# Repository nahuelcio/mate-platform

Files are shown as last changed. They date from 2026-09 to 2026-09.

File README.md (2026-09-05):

# mate-platform 🧉

IoT platform for smart mate sharing sessions powered by ESP32, embedded sensors, web server API, and MCP notification agent for Claude Code and chat channels.

---

## Overview

`mate-platform` automates round management for drinking mate:
- **Automatic turn passing:** When the mate is picked up from the dock base, a timer starts. Once placed back on the dock, the round advances automatically to the next person.
- **Hold alarm:** If a participant retains the mate longer than the allowed duration, an acoustic alarm sounds through the buzzer and displays a warning on the OLED screen.
- **Automated tilt mechanism:** An SG90 micro-servo tilts the base to 45° to assist with water pouring and herbal infusion positioning.
- **Voice integration ("Thanks" detection):** When someone says *"gracias"*, they leave the round, and the turn advances.
- **Notifications & Chat:** Multi-channel notification watcher (macOS native banners, Discord, Slack, Telegram) and Model Context Protocol (MCP) server for Claude Code.

---

## Hardware Components & Pinout

ESP32 DOIT 30-PIN Dev Board configuration:

| Component | Function | ESP32 Pins | Protocol / Mode |
| :--- | :--- | :--- | :--- |
| **SSD1306 (0.96" OLED)** | Turn display, timer & alert banner | `SDA: GPIO 21`, `SCL: GPIO 22` | I2C (`0x3C`) |
| **GY-521 (MPU6050)** | Accelerometer & gyro for tilt detection | `SDA: GPIO 21`, `SCL: GPIO 22` | I2C (`0x68`) |
| **SG90 Micro Servo** | Automatic 45° tilt mechanism | `PWM: GPIO 13`, `VIN (5V)`, `GND` | PWM |
| **HC-SR04** | Ultrasonic proximity sensor | `TRIG: GPIO 5`, `ECHO: GPIO 18` | Digital I/O |
| **GY-MAX9814** | Microphone with automatic gain | `OUT: GPIO 35` (ADC1), `3V3`, `GND` | Analog (ADC1 safe with Wi-Fi) |
| **Active Buzzer** | Acoustic anti-delay alarm | `GPIO 19`, `GND` | Digital / PWM `tone()` |
| **Base Dock Switch** | Mate present / lifted detection | `GPIO 4`, `GND` | Digital In (`INPUT_PULLUP`) |

---

## REST API (ESP32 Web Server)

| Method | Endpoint | Description |
| :--- | :--- | :--- |
| `GET` | `/status` | Returns round status, current turn, dock state, distance, and participant list |
| `POST` | `/round/config` | Sets participant names: `{"names": ["Nahuel", "Santi", "Flor"]}` |
| `POST` | `/round/thanks` | Removes participant who said thanks: `?name=Nahuel` |
| `POST` | `/round/next` | Manually advances to the next turn |
| `POST` | `/servo/tilt` | Adjusts SG90 tilt angle: `?angle=45` |

---

## Claude Code MCP Integration (`mcp-mate-platform`)

The included MCP server exposes tools directly to Claude Code.

### Available Tools:
1. `mate_status`: Consultar estado del mate y a quién le toca.
2. `mate_tilt_pour`: Inclinar el mate a 45° con el servo para cebar.
3. `mate_thanks`: Registrar que alguien dijo "gracias" y retirarlo de la ronda.
4. `mate_next`: Pasar el turno manualmente.
5. `mate_configure`: Configurar la lista de personas de la ronda.

### Registering with Claude Code:

```bash
claude mcp add mate-platform -- node /path/to/mate-platform/mcp-mate-platform/dist/index.js
```

For real hardware over local Wi-Fi, specify the target IP:
```bash
claude mcp add mate-platform -- node /path/to/mate-platform/mcp-mate-platform/dist/index.js --env MATE_PLATFORM_URL=http://192.168.1.50
```

### Notifications & Chat Watcher (macOS, Discord, Slack, Telegram):

Run in a background terminal:
```bash
cd mcp-mate-platform

# With optional Chat Webhooks:
export DISCORD_WEBHOOK_URL="https://discord.com/api/webhooks/..."
export SLACK_WEBHOOK_URL="https://hooks.slack.com/services/..."

npm run notify -- --sound --pomodoro 3
```

---

## Simulation with Wokwi

1. Open `diagram.json` in VS Code.
2. Press `F1` / `Cmd + Shift + P` and select **`Wokwi: Start Simulator`**.
3. Ports are forwarded automatically to `http://localhost:8180`.

---

## License

MIT

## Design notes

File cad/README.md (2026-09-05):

# mate-platform: 3D CAD Blueprint & Assembly Guide

Este documento detalla la arquitectura mecánica, despiece, tolerancias y especificaciones para fabricar las piezas de la estación inteligente de mate en impresión 3D (FDM / SLA) o para su importación directa en Shapr3D.

---

## 1. Arquitectura del Conjunto (4 Módulos)

```
                       [ MATE / CALABAZA ]
                                │
                      (Pulsador de Presencia)
                                │
    ┌────────────────────────────────────────────────────────┐
    │  PIEZA 1: Cuna Basculante 45° (Tilting Cradle)         │
    │  - Asiento cónico Ø 78 mm para el mate                 │
    │  - Pernos de pivote Ø 6 mm integrados                  │
    │  - Alojamiento inferior para IMU GY-521 (MPU6050)      │
    │  - Ojo de biela para brazo de servo SG90               │
    └───────────────────────────┬────────────────────────────┘
                                │ Eje de Giro (Pivote 45°)
    ┌───────────────────────────┴────────────────────────────┐
    │  PIEZA 2: Carcasa Superior & Sensores (Sensor Fascia)  │
    │  - Bisel para Pantalla OLED SSD1306 a 30°              │
    │  - Soportes cilíndricos para HC-SR04 (ojos ultrasonido)│
    │  - Guía acústica para micrófono GY-MAX9814             │
    │  - Bancadas de apoyo para los pernos de giro           │
    └───────────────────────────┬────────────────────────────┘
                                │ Encastre M3 / Snap-Fit
    ┌───────────────────────────┴────────────────────────────┐
    │  PIEZA 3: Chasis Principal (Main Enclosure Base)       │
    │  - Cuna y correderas para placa ESP32 (30 pines)       │
    │  - Bahía de fijación rígida para Micro Servo SG90      │
    │  - Cámara acústica de resonancia para Buzzer 12mm      │
    │  - Pasacables internos con amarre para zunchos         │
    │  - Salida trasera para cable Micro-USB / Type-C        │
    └───────────────────────────┬────────────────────────────┘
                                │ 4x Tornillos M3 avellanados
    ┌───────────────────────────┴────────────────────────────┐
    │  PIEZA 4: Tapa Inferior de Servicio (Bottom Lid)       │
    │  - Ranuras de ventilación tipo persiana (louver vents) │
    │  - 4x Alojamientos para patas de silicona (Ø 12 x 2 mm)│
    │  - Acceso directo para mantenimiento y cableado        │
    └────────────────────────────────────────────────────────┘
```

---

## 2. Dimensiones y Medidas Críticas (Nominales & Tolerancias)

| Componente | Medida Real (mm) | Tolerancia 3D (Cavitación) | Detalle de Encastre |
| :--- | :--- | :--- | :--- |
| **Mate / Vaso** | Ø 60 a 76 mm | Asiento Ø 78 mm cónico | Admite mates de calabaza, madera o acero térmico |
| **ESP32 DOIT 30-Pin** | 51.5 x 28.5 x 12.0 mm | Riel de 52.5 x 29.5 mm (+1.0mm) | Deslizamiento suave sobre guías laterales |
| **OLED 0.96" SSD1306** | 27.0 x 27.5 x 3.5 mm | Bisel de 24.5 x 14.5 mm (área activa) | Inclinado a 30° hacia el usuario para lectura fácil |
| **Servo SG90** | 22.8 x 12.2 x 24.5 mm | Bolsillo de 23.5 x 12.8 mm (+0.6mm) | Fijado con orejeras de 2 tornillos M2 |
| **Sensor HC-SR04** | 45.2 x 20.4 mm, conos Ø 16 mm | 2x orificios de Ø 16.5 mm c-to-c 26 mm | Alojamiento a presión frontal para censar presencia |
| **Micrófono GY-MAX9814** | 25.5 x 14.2 mm, cápsula Ø 6mm | Cavidad frontal + rejilla acústica | Aislado mecánicamente de la vibración del servo |
| **Buzzer 12mm** | Ø 12.0 mm x 9.5 mm | Cámara resonante Ø 14.0 mm | Salida de audio acústica en la base |
| **Switch Base (Dock)** | KW12 (19.8 x 6.4 x 10.2 mm) | Soporte con resorte de retorno | Se activa con > 25 g al apoyar el mate |

---

## 3. Archivos STL Generados y Listos para Imprimir

Ubicación: `/cad/models/`

1. **`01_tilting_cradle_45deg.stl`**
   - Peso estimado: ~28 g PLA.
   - Tiempo de impresión: ~1h 45m.
   - Soportes recomendados: Soportes tipo árbol solo en los pernos de pivote.
2. **`02_main_enclosure_base.stl`**
   - Peso estimado: ~65 g PLA.
   - Tiempo de impresión: ~3h 30m.
   - Infill: 20% Gyroid (para máxima rigidez y resonancia del buzzer).
3. **`03_upper_sensor_fascia.stl`**
   - Peso estimado: ~38 g PLA.
   - Tiempo de impresión: ~2h 15m.
   - Permite montar la pantalla inclinada y los sensores frontales.
4. **`04_bottom_service_lid.stl`**
   - Peso estimado: ~22 g PLA.
   - Tiempo de impresión: ~1h 10m.
   - Fondo plano, no requiere soportes.

---

## 4. Parámetros de Impresión Recomendados (FDM)

- **Material:** PLA, PLA+ o PETG (recomendado PETG si se expone a salpicaduras de agua caliente).
- **Altura de capa:** `0.20 mm` (ó `0.16 mm` para mejor acabado en las curvas de la cuna).
- **Perímetros (Paredes):** 4 a 6 perímetros (`1.6 mm - 2.4 mm`) para tornillos e insertos de rosca M3.
- **Relleno (Infill):** `20% - 25%` Gyroid o Honeycomb.
- **Insertos:** Agujeros preparados para insertos de latón M3 (roscado en caliente / calor con cautín).

---

## 5. Edición y Ajustes Paramétricos

Para regenerar o cambiar cualquier medida (por ejemplo ampliar el diámetro del mate a 85mm o ajustar el ángulo del display):
```bash
python3 cad/generator.py
```
El script exporta los binarios STL estándar que pueden abrirse directamente en **Shapr3D**, **Bambu Studio**, **PrusaSlicer**, **OrcaSlicer** o **Cura**.

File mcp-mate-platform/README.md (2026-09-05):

# mcp-ymate 🧉

Servidor **MCP** para que **Claude Code** (y Claude Desktop) controlen el **ESP32 yMate** — el mate con ronda automática, sensor de apoyo, servo de cebado y alerta de demora.

Habla con el webserver del ESP32 (proyecto en `../esp32`, simulado con Wokwi):

| Endpoint del ESP32 | Uso |
|---|---|
| `GET /status` | Estado de la ronda |
| `POST /ronda/config` | Armar ronda: `{ "nombres": [...] }` |
| `POST /ronda/gracias` | Sacar a quien dijo gracias (`?nombre=` o el actual) |
| `POST /servo/mover` | Inclinar el servo (`?angulo=`, 0–90, default 45) |

> Importante: el firmware lee los parámetros con `server.arg()`, que se resuelve
> con el **query string**. Este cliente manda los parámetros por query y además
> repite el body JSON para máxima compatibilidad.

## Requisitos

- Node.js ≥ 18 (probado con Node 26)
- La simulación de Wokwi corriendo con el reenvío `localhost:8180 → target:80`,
  o el ESP32 real en tu red (usá `YMATE_BASE_URL`)

## Instalación

```bash
cd /Users/nahuelcioffi/Proyectos/esp32/mcp-ymate
npm install
npm run build     # genera dist/
```

## Registrarlo en Claude Code

### Opción A: `claude mcp add` (recomendada)

```bash
# Si el ESP32 está simulado en localhost:8180 (Wokwi):
claude mcp add ymate -- node /Users/nahuelcioffi/Proyectos/esp32/mcp-ymate/dist/index.js

# Si el ESP32 real está en tu red:
claude mcp add ymate --env YMATE_BASE_URL=http://192.168.1.50 -- node /Users/nahuelcioffi/Proyectos/esp32/mcp-ymate/dist/index.js

# Alcance: --scope local (solo este proyecto) o --scope user (todos tus proyectos)
```

### Opción B: `.mcp.json` en la raíz del proyecto

```json
{
  "mcpServers": {
    "ymate": {
      "command": "node",
      "args": ["/Users/nahuelcioffi/Proyectos/esp32/mcp-ymate/dist/index.js"],
      "env": { "YMATE_BASE_URL": "http://localhost:8180" }
    }
  }
}
```

### Opción C: config global de Claude Code

```bash
claude mcp add --scope user ymate -- node /Users/nahuelcioffi/Proyectos/esp32/mcp-ymate/dist/index.js
```

### Registrarlo en Claude Desktop

`claude_desktop_config.json` (macOS: `~/Library/Application Support/Claude/claude_desktop_config.json`):

```json
{
  "mcpServers": {
    "ymate": {
      "command": "node",
      "args": ["/Users/nahuelcioffi/Proyectos/esp32/mcp-ymate/dist/index.js"],
      "env": { "YMATE_BASE_URL": "http://localhost:8180" }
    }
  }
}
```

Verificá con `claude mcp list` (Claude Code) o reiniciá Claude Desktop.

## Herramientas MCP

| Herramienta | Qué hace |
|---|---|
| `mate_status` | Estado de la ronda: quién tiene el turno, si el mate está apoyado o en mano, alerta de demora, distancia y participantes |
| `mate_cebar` | Inclina el servo (ceba el mate). `{ angulo?: 0–90 }`, default 45 |
| `mate_gracias` | Registra el "gracias" de alguien y lo saca de la ronda. `{ nombre?: string }`, default: el actual |
| `mate_siguiente` | Pasa el turno al siguiente (rota la lista vía `/ronda/config`) |
| `mate_configurar` | Arma una ronda nueva. `{ nombres: string[] }` (máx. 10) |

Después de registrarlo, decile a Claude algo como:

> Usá `mate_status`, pasale el turno a Santi con `mate_siguiente` y cebá con `mate_cebar`.

## Notificador / Pomodoro matero (terminal)

Un proceso aparte que vigila `/status` cada pocos segundos y avisa por consola
cuando alguien levanta el mate, lo devuelve, cambia el turno o salta la alerta
de demora. Con `--pomodoro MIN` recuerda pasar el mate cada `MIN` minutos.

```bash
npm run notify                                  # vigila cada 5 s
npm run notify -- --interval 10 --pomodoro 3 --sound
npm run notify -- --once                        # imprime el estado y sale (útil para hooks)
YMATE_BASE_URL=http://192.168.1.50 npm run notify
```

### Como hook de Claude Code

Para que un agente "matero" vigile la ronda en background, agregá esto a tu
`.claude/settings.json` (o la config de tu proyecto):

```json
{
  "hooks": {
    "PreToolUse": [
      {
        "matcher": "Bash(npm run notify|node .*pomodoro)",
        "hooks": [
          {
            "type": "command",
            "command": "node /Users/nahuelcioffi/Proyectos/esp32/mcp-ymate/dist/pomodoro.js --once"
          }
        ]
      }
    ]
  }
}
```

O simplemente dejalo corriendo en otra pestaña de la terminal con `npm run notify`.

## Desarrollo y verificación

```bash
npm run mock      # mock del ESP32 en http://localhost:8180 (replica main.cpp)
npm run smoke     # test E2E: mock + handshake MCP por stdio + las 5 herramientas
npm run notify -- --once   # prueba el notificador contra el mock
```

La base URL se resuelve así: `YMATE_BASE_URL` → `ESP32_URL` → `http://localhost:8180`.

## Estructura

```
mcp-ymate/
├── src/
│   ├── index.ts       # servidor MCP (stdio) con las 5 herramientas
│   ├── client.ts      # cliente HTTP contra el ESP32 (query + body)
│   ├── config.ts      # resolución de YMATE_BASE_URL y tipos
│   └── pomodoro.ts    # notificador / pomodoro matero en terminal
├── scripts/
│   ├── mock-esp32.js  # mock fiel del firmware para desarrollo
│   └── smoke.mjs      # smoke test end-to-end por stdio
├── package.json
└── tsconfig.json
```

## Solución de problemas

- **"No hay respuesta del ESP32"**: la simulación de Wokwi no está corriendo, o el
  ESP32 real está en otra IP. Ajustá `YMATE_BASE_URL`.
- **No aparecen las herramientas**: reiniciá Claude Code / Claude Desktop después
  de registrar el server, y verificá con `claude mcp list`.
- **El ángulo no cambia con body JSON**: el firmware usa `server.arg()`, que
  prioriza el query string; este cliente siempre manda `?angulo=` también.

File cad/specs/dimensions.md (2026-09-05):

# Mechanical Dimensions & Component Tolerances

All dimensions in millimeters (mm). Tolerances for FDM 3D printing (PLA/PETG, 0.4mm nozzle, 0.2mm layer height) included.

---

## 1. Electronic Components Dimensions

### 1.1 ESP32 DOIT DevKit V1 (30-pin)
- PCB Outline: `51.5 mm (L) × 28.5 mm (W) × 12.0 mm (H)` (including pin headers).
- Pin pitch: `2.54 mm`. Row spacing: `25.4 mm (1.0")`.
- Micro-USB connector protrusion: `1.5 mm` beyond PCB edge.
- Mounting hole spacing: `46.0 mm × 23.0 mm`, hole diameter: `2.8 mm` (for M2.5 / self-tapping screws).
- Clearance envelope for cad cradle: `53.0 mm × 30.0 mm × 14.0 mm`.

### 1.2 SSD1306 0.96" OLED I2C Display
- PCB Size: `27.0 mm (W) × 27.5 mm (H) × 3.5 mm (D)`.
- Active glass screen: `24.0 mm × 14.0 mm` (viewable area: `21.74 mm × 10.86 mm`).
- Screen offset from PCB top: `4.5 mm`.
- Mounting holes: 4× `M2` holes (`2.0 mm`), center-to-center: `23.0 mm (W) × 23.5 mm (H)`.
- Front bezel cutout required: `24.5 mm × 14.5 mm`, inner recess depth `1.8 mm`.

### 1.3 SG90 Micro Servo
- Body Dimensions: `22.8 mm (L) × 12.2 mm (W) × 24.5 mm (H)` (overall height with output spline: `28.5 mm`).
- Mounting flange: `32.0 mm (L) × 12.2 mm (W) × 2.5 mm (T)` at height `16.0 mm` from base.
- Flange mounting screw pitch: `28.0 mm` (2× holes, `2.0 mm` dia).
- Output shaft center: `5.5 mm` from one edge, diameter `4.8 mm` (21T spline).
- Horn swing radius: `15.0 mm` clearance envelope.

### 1.4 GY-521 (MPU6050 6-DoF IMU)
- PCB Dimensions: `20.5 mm (L) × 15.6 mm (W) × 3.2 mm (H)`.
- Mounting holes: 2× `M3` holes (`3.0 mm` dia) spaced `15.0 mm` apart.
- Placement: Mounted directly under the tilting cradle to track real inclination.

### 1.5 HC-SR04 Ultrasonic Distance Sensor
- PCB Dimensions: `45.2 mm (L) × 20.4 mm (W) × 15.0 mm (H)`.
- Transducers (Transmitter + Receiver): 2× cylinders, `16.0 mm` outer diameter each.
- Transducer center-to-center distance: `26.0 mm`.
- Transducer protrusion above PCB: `12.5 mm`.
- Front plate cutouts: 2× `16.5 mm` circular holes spaced `26.0 mm` center-to-center.

### 1.6 GY-MAX9814 Microphone Module
- PCB Dimensions: `25.5 mm (L) × 14.2 mm (W) × 8.0 mm (H)`.
- Mic capsule diameter: `6.0 mm`, protrusion: `3.0 mm`.
- Front sound grille aperture: 3× `1.5 mm` acoustic slot array.

### 1.7 Passive/Active Buzzer Module (12mm)
- Body: Cylinder `12.0 mm` diameter × `9.5 mm` height.
- Sound port: `2.0 mm` central top hole.
- Internal acoustic cavity: `14.0 mm` chamber with sound director funnel.

### 1.8 Microswitch / Limit Switch (Dock Sensor)
- KW12 / Omron style micro lever switch: `19.8 mm (L) × 6.4 mm (W) × 10.2 mm (H)`.
- Lever arm length: `18.0 mm` with roller or curved tip.
- Actuation stroke: `1.2 mm - 1.8 mm`.
- Pre-travel contact: Triggered by 25g+ mate weight resting on dock plate.

---

## 2. Platform Architecture (4 Main Assemblies)

```
       +---------------------------------------------+
       |             MATE CUP (Calabaza/Termo)       |
       +---------------------------------------------+
                            |
                   [Dock Switch Lever]
                            |
  +-------------------------------------------------------+
  |  PART 1: Tilting Cradle (Cuna Basculante 45°)         |
  |  - Inner Ø 78 mm cup seat                             |
  |  - Built-in GY-521 IMU pocket                         |
  |  - Pivot trunnion pins (Ø 6 mm)                       |
  |  - Servo push-rod linkage receiver                    |
  +-------------------------------------------------------+
                            |
          Pivot Axis (Ø 6mm Pin) + SG90 Servo Arm
                            |
  +-------------------------------------------------------+
  |  PART 2: Upper Housing & Sensor Ring                  |
  |  - HC-SR04 dual front apertures (Ø 16.5 mm)           |
  |  - SSD1306 0.96" OLED bezel angled at 30°             |
  |  - Mic acoustic duct for GY-MAX9814                   |
  |  - Trunnion pivot supports (Left & Right)             |
  +-------------------------------------------------------+
                            |
                    Snap-fit / M3 Standoffs
                            |
  +-------------------------------------------------------+
  |  PART 3: Main Base Enclosure (Cuerpo Principal)       |
  |  - ESP32 slide-in rails with USB-C / micro-USB port   |
  |  - SG90 servo rigid pocket & cable raceways           |
  |  - Internal cable routing channels & tie anchors      |
  |  - Buzzer resonant sound chamber                      |
  +-------------------------------------------------------+
                            |
                    4x M3 Threaded Inserts
                            |
  +-------------------------------------------------------+
  |  PART 4: Bottom Service Lid (Tapa Inferior)           |
  |  - 4x Non-slip rubber feet recesses (Ø 10 mm x 2 mm)  |
  |  - Passive cooling vents (angled louvers)             |
  |  - Access to reset/boot buttons                       |
  +-------------------------------------------------------+
```

---

## 3. Clearances & 3D Print Tolerances

- **FDM Press-fit (tight):** Component nominal + `0.15 mm`.
- **FDM Sliding-fit / Pivot:** Shaft nominal - `0.20 mm`, Hole nominal + `0.25 mm` (Total clearance `0.45 mm`).
- **Snap-fit cantilever tabs:** Width `5.0 mm`, thickness `1.6 mm`, length `12.0 mm`, hook depth `0.8 mm`.
- **Wall thickness guidelines:**
  - Structural outer shell: `2.4 mm` (6 perimeters with 0.4mm nozzle).
  - Internal ribs & dividers: `1.6 mm` (4 perimeters).
  - Component cradle clips: `1.2 mm`.
- **M3 Threaded heat-set inserts:** Hole diameter `4.2 mm`, depth `5.5 mm`.

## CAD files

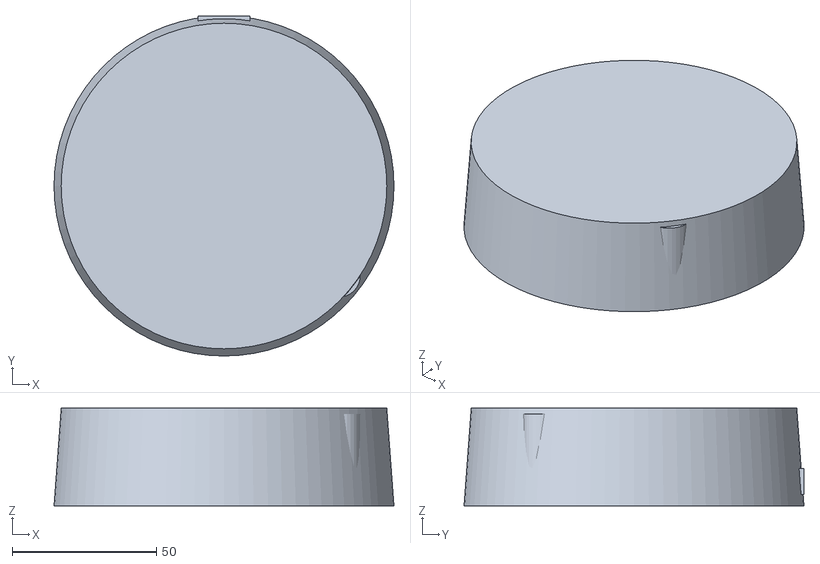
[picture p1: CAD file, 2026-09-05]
cad/models/02_main_enclosure_base.stl
118.0 x 118.0 x 34.0

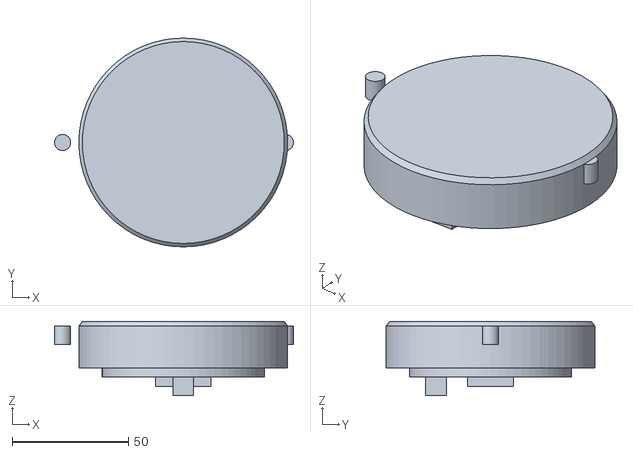
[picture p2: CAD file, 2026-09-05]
cad/models/01_tilting_cradle_45deg.stl
103.0 x 90.0 x 32.0

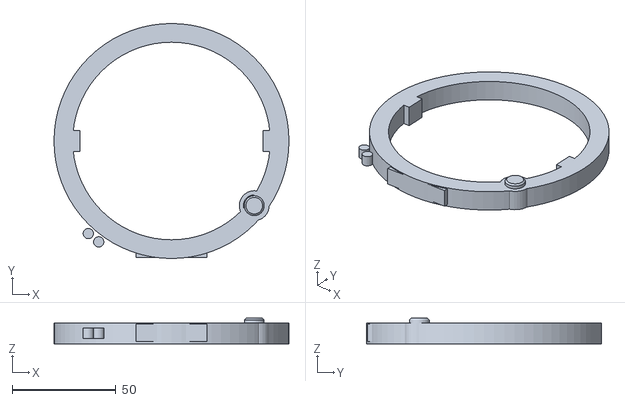
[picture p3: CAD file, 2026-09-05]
cad/models/03_upper_sensor_fascia.stl
113.0 x 113.0 x 12.3

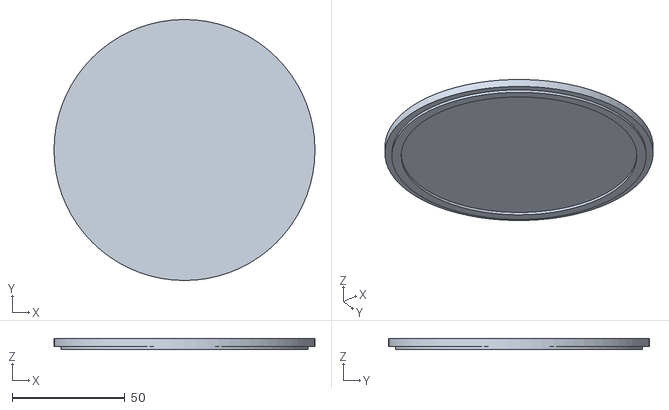
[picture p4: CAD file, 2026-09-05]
cad/models/04_bottom_service_lid.stl
116.0 x 116.0 x 4.70

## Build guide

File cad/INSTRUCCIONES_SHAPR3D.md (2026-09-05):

# Importar en Shapr3D - mate-platform

La ventana de Finder ya está abierta con los 4 archivos STL:
`/Users/nahuelcioffi/Proyectos/esp32/cad/models`

## Pasos rápidos en Shapr3D:

1. En Shapr3D, hace clic en **"New design"** (o **Cmd + N**).
2. Seleccioná los 4 archivos en la ventana de Finder que tenés abierta:
   - `01_tilting_cradle_45deg.stl`
   - `02_main_enclosure_base.stl`
   - `03_upper_sensor_fascia.stl`
   - `04_bottom_service_lid.stl`
3. **Arrastralos y soltalos (Drag & Drop)** directamente adentro del lienzo 3D de Shapr3D.
   - O desde el menú: **File > Import...** (o **Cmd + I**) y elegí los archivos de esa carpeta.

## Unidades al importar:
- Elegí **Millimeters (mm)** si te pregunta.

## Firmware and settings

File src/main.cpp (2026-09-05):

#include <Arduino.h>
#include <WiFi.h>
#include <WebServer.h>
#include <Wire.h>
#include <Adafruit_GFX.h>
#include <Adafruit_SSD1306.h>
#include <Adafruit_MPU6050.h>
#include <Adafruit_Sensor.h>
#include <ESP32Servo.h>
#include <ArduinoJson.h>

// --- OLED SSD1306 DISPLAY (I2C) ---
#define SCREEN_WIDTH 128
#define SCREEN_HEIGHT 64
Adafruit_SSD1306 display(SCREEN_WIDTH, SCREEN_HEIGHT, &Wire, -1);

// --- GY-521 (MPU6050) ACCELEROMETER / GYROSCOPE ---
Adafruit_MPU6050 mpu;
bool mpuAvailable = false;

// --- SG90 MICRO SERVO (TILT / POURING MECHANISM) ---
Servo sg90;
const int PIN_SERVO_SG90 = 13;

// --- HC-SR04 ULTRASONIC SENSOR ---
const int PIN_TRIG = 5;
const int PIN_ECHO = 18;

// --- GY-MAX9814 MICROPHONE (ANALOG OUT) ---
// Dedicated ADC1 input pin on ESP32 (safe to use while Wi-Fi is active)
const int PIN_MIC_OUT = 35;

// --- BUZZER / SPEAKER (DELAY ALARM) ---
const int PIN_BUZZER = 19;

// --- STATUS LED / BREATHING RING (INDICATOR) ---
// Solid green/blue: ready/docked. Breathing blue: drinking. Blinking red: delay alarm!
const int PIN_LED_STATUS = 2;

// --- BASE DOCK SWITCH (MECHANICAL / BUTTON INPUT) ---
const int PIN_BTN_BASE = 4;

// --- MULTIFUNCTION PHYSICAL BUTTON (ALUMINUM CROWN) ---
// Short press: manual next turn ("mate_next")
// Long press (>2s): mute alarm / toggle round pause
const int PIN_BTN_ACTION = 15;
unsigned long btnActionPressTime = 0;
bool btnActionLastState = HIGH;

WebServer server(80);

// --- ROUND / SESSION STATE ---
#define MAX_PARTICIPANTS 10
String participants[MAX_PARTICIPANTS] = {"Nahuel", "Santi", "Flor", "Mati"};
int totalParticipants = 4;
int currentTurn = 0;

bool mateOnDock = true;
bool delayAlarmActive = false;
unsigned long liftedTimestamp = 0;
const unsigned long DELAY_TIMEOUT_MS = 15000; // 15s for quick simulation test (300000 for 5 min in prod)

int currentTiltAngle = 0;

// Read distance in centimeters via HC-SR04
float readDistanceCm() {
  digitalWrite(PIN_TRIG, LOW);
  delayMicroseconds(2);
  digitalWrite(PIN_TRIG, HIGH);
  delayMicroseconds(10);
  digitalWrite(PIN_TRIG, LOW);
  long duration = pulseIn(PIN_ECHO, HIGH, 25000);
  if (duration == 0) return 999.0;
  return duration * 0.034 / 2.0;
}

// Read peak-to-peak microphone amplitude from GY-MAX9814
int readMicAmplitude(int samples = 50) {
  int minVal = 4095;
  int maxVal = 0;
  for (int i = 0; i < samples; i++) {
    int v = analogRead(PIN_MIC_OUT);
    if (v < minVal) minVal = v;
    if (v > maxVal) maxVal = v;
    delayMicroseconds(100);
  }
  return (maxVal - minVal);
}

void updateDisplay(const String& line1, const String& line2 = "") {
  display.clearDisplay();
  display.setTextSize(1);
  display.setTextColor(SSD1306_WHITE);

  display.setCursor(0, 0);
  display.print("= Ronda de Mate =");

  display.setCursor(0, 16);
  display.setTextSize(2);
  display.print((totalParticipants > 0) ? participants[currentTurn] : "Nadie");

  display.setTextSize(1);
  display.setCursor(0, 40);
  display.print(line1);

  if (line2.length() > 0) {
    display.setCursor(0, 52);
    display.print(line2);
  }

  display.display();
}

void nextTurn() {
  if (totalParticipants > 0) {
    currentTurn = (currentTurn + 1) % totalParticipants;
    Serial.printf("[MatePlatform] Proximo turno: %s\n", participants[currentTurn].c_str());
    updateDisplay("Turno de:", participants[currentTurn]);
  }
}

void removeParticipant(const String& name) {
  int idx = -1;
  for (int i = 0; i < totalParticipants; i++) {
    if (participants[i].equalsIgnoreCase(name)) {
      idx = i;
      break;
    }
  }

  if (idx != -1) {
    Serial.printf("[MatePlatform] '%s' dijo gracias! Queda afuera de la ronda.\n", participants[idx].c_str());
    for (int i = idx; i < totalParticipants - 1; i++) {
      participants[i] = participants[i + 1];
    }
    totalParticipants--;
    if (currentTurn >= totalParticipants) currentTurn = 0;
    updateDisplay("Dijo gracias!", "Chau " + name);
  }
}

// Servo tilt angle helper
void setTiltAngle(int targetAngle) {
  currentTiltAngle = constrain(targetAngle, 0, 90);
  sg90.write(currentTiltAngle);
  Serial.printf("[SG90] Inclinacion ajustada a: %d grados\n", currentTiltAngle);
}

// --- HTTP ENDPOINTS (100% IN ENGLISH) ---
void handleStatus() {
  JsonDocument doc;
  doc["turn"] = (totalParticipants > 0) ? participants[currentTurn] : "None";
  doc["isDocked"] = mateOnDock;
  doc["delayAlarm"] = delayAlarmActive;
  doc["distance_cm"] = readDistanceCm();
  doc["mic_amplitude"] = readMicAmplitude(20);
  doc["tilt_angle"] = currentTiltAngle;

  if (mpuAvailable) {
    sensors_event_t a, g, temp;
    mpu.getEvent(&a, &g, &temp);
    doc["accel_x"] = a.acceleration.x;
    doc["accel_y"] = a.acceleration.y;
    doc["accel_z"] = a.acceleration.z;
  }

  JsonArray arr = doc["participants"].to<JsonArray>();
  for (int i = 0; i < totalParticipants; i++) {
    arr.add(participants[i]);
  }

  String res;
  serializeJson(doc, res);
  server.send(200, "application/json", res);
}

// POST /round/config -> {"names": ["Nahuel", "Santi"]}
void handleConfigRound() {
  if (!server.hasArg("plain")) {
    server.send(400, "text/plain", "Missing JSON body");
    return;
  }
  JsonDocument doc;
  DeserializationError err = deserializeJson(doc, server.arg("plain"));
  if (err) {
    server.send(400, "text/plain", "Invalid JSON");
    return;
  }

  JsonArray names = doc["names"];
  totalParticipants = 0;
  for (JsonVariant v : names) {
    if (totalParticipants < MAX_PARTICIPANTS) {
      participants[totalParticipants++] = v.as<String>();
    }
  }
  currentTurn = 0;
  updateDisplay("Ronda lista!", participants[currentTurn]);
  server.send(200, "application/json", "{\"status\":\"ok\"}");
}

// POST /round/thanks -> ?name=Nahuel or body
void handleThanks() {
  String name = server.arg("name");
  if (name.length() == 0 && totalParticipants > 0) {
    name = participants[currentTurn];
  }
  removeParticipant(name);
  server.send(200, "application/json", "{\"status\":\"removed\",\"name\":\"" + name + "\"}");
}

// POST /round/next
void handleNextTurn() {
  nextTurn();
  server.send(200, "application/json", "{\"status\":\"ok\",\"turn\":\"" + ((totalParticipants > 0) ? participants[currentTurn] : "") + "\"}");
}

// POST /servo/tilt?angle=45
void handleServoTilt() {
  String angleStr = server.arg("angle");
  int ang = angleStr.length() > 0 ? angleStr.toInt() : 45;
  setTiltAngle(ang);
  server.send(200, "application/json", "{\"status\":\"ok\",\"angle\":" + String(ang) + "}");
}

void setup() {
  Serial.begin(115200);

  pinMode(PIN_BTN_BASE, INPUT_PULLUP);
  pinMode(PIN_BTN_ACTION, INPUT_PULLUP);
  pinMode(PIN_TRIG, OUTPUT);
  pinMode(PIN_ECHO, INPUT);
  pinMode(PIN_BUZZER, OUTPUT);
  pinMode(PIN_LED_STATUS, OUTPUT);
  pinMode(PIN_MIC_OUT, INPUT);
  digitalWrite(PIN_BUZZER, LOW);
  digitalWrite(PIN_LED_STATUS, HIGH); // LED ON at boot

  // Initialize SG90 servo
  sg90.attach(PIN_SERVO_SG90);
  setTiltAngle(0);

  // Initialize I2C bus (OLED & GY-521)
  Wire.begin(21, 22);

  if (display.begin(SSD1306_SWITCHCAPVCC, 0x3C)) {
    updateDisplay("Iniciando...", "Conectando WiFi");
  }

  // Initialize GY-521 accelerometer / gyroscope
  if (mpu.begin()) {
    mpuAvailable = true;
    mpu.setAccelerometerRange(MPU6050_RANGE_8_G);
    Serial.println("[GY-521] MPU6050 initialized.");
  } else {
    Serial.println("[GY-521] MPU6050 not detected.");
  }

  // Connect Wi-Fi
  WiFi.begin("Wokwi-GUEST", "");
  Serial.println("Connecting to Wi-Fi...");
  while (WiFi.status() != WL_CONNECTED) {
    delay(200);
    Serial.print(".");
  }
  Serial.printf("\nWi-Fi Connected! IP: %s\n", WiFi.localIP().toString().c_str());

  // Web server routes (pure English endpoints)
  server.on("/status", HTTP_GET, handleStatus);
  server.on("/round/config", HTTP_POST, handleConfigRound);
  server.on("/round/thanks", HTTP_POST, handleThanks);
  server.on("/round/next", HTTP_POST, handleNextTurn);
  server.on("/servo/tilt", HTTP_POST, handleServoTilt);
  server.on("/servo/tilt", HTTP_GET, handleServoTilt);
  server.begin();

  updateDisplay("Turno de:", participants[currentTurn]);
}

void loop() {
  server.handleClient();

  // 1. Detect dock presence (LOW = docked, HIGH = lifted)
  bool docked = (digitalRead(PIN_BTN_BASE) == LOW);

  if (mateOnDock && !docked) {
    // Mate lifted to drink
    mateOnDock = false;
    liftedTimestamp = millis();
    delayAlarmActive = false;
    Serial.printf("[MatePlatform] %s esta tomando.\n", participants[currentTurn].c_str());
    updateDisplay("Tomando...", participants[currentTurn]);

    // Tilt servo to 45 degrees
    setTiltAngle(45);
  }
  else if (!mateOnDock && docked) {
    // Mate placed back on dock: reset angle and advance turn
    mateOnDock = true;
    delayAlarmActive = false;
    noTone(PIN_BUZZER);
    setTiltAngle(0);
    Serial.println("[MatePlatform] Mate devuelto a la base.");
    nextTurn();
    delay(400); // Debounce
  }

  // 2. Physical Button Handling (GPIO 15)
  bool btnState = digitalRead(PIN_BTN_ACTION);
  if (btnActionLastState == HIGH && btnState == LOW) {
    // Button pressed down
    btnActionPressTime = millis();
  } else if (btnActionLastState == LOW && btnState == HIGH) {
    // Button released
    unsigned long duration = millis() - btnActionPressTime;
    if (duration > 2000) {
      // Long press: Mute buzzer alarm or reset
      if (delayAlarmActive) {
        delayAlarmActive = false;
        noTone(PIN_BUZZER);
        Serial.println("[Button] Long press: Alarm muted!");
        updateDisplay("Alarma silenciada", participants[currentTurn]);
      }
    } else if (duration > 50) {
      // Short press: Manual Next Turn
      Serial.println("[Button] Short press: Manual next turn!");
      nextTurn();
    }
  }
  btnActionLastState = btnState;

  // 3. Alarm trigger if mate is held past timeout
  if (!mateOnDock && !delayAlarmActive && (millis() - liftedTimestamp > DELAY_TIMEOUT_MS)) {
    delayAlarmActive = true;
    tone(PIN_BUZZER, 1000); // Sound alarm buzzer
    Serial.printf("[MatePlatform] ALARMA: %s se colgo con el mate!\n", participants[currentTurn].c_str());
    updateDisplay("ALARMA!", "Larga el mate!!");
  }

  // 4. Status LED Feedback
  if (delayAlarmActive) {
    // Fast blink during alarm
    digitalWrite(PIN_LED_STATUS, (millis() / 250) % 2);
  } else if (!mateOnDock) {
    // Pulse/breathing effect while drinking
    digitalWrite(PIN_LED_STATUS, (millis() / 500) % 2);
  } else {
    // Solid steady ON when docked/ready
    digitalWrite(PIN_LED_STATUS, HIGH);
  }

  delay(50);
}

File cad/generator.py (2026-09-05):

"""
Generador CAD 3D de alta gama para mate-platform:
ESTÉTICA: "Dock MagSafe Circular Fino"
- Cuenco hundido 22 mm anti-caídas (abrazamiento cónico del mate).
- Pantalla OLED SSD1306 (0.96") rasante frontal.
- Botón físico cilíndrico de aluminio CNC (Ø 12 mm) para pasar turno manual (GPIO 15).
- NUEVO: LED INDICADOR FRONTAL (Pinhole rasante Ø 2.5 mm con guía de luz acrílica difusa, GPIO 2).
- NUEVO: SLOT PARA PARLANTE / BUZZER CON REJILLA INFERIOR OCULTA:
  * Cámara acústica orientada hacia la base inferior (down-firing speaker).
  * Rejilla de audio micro-ranurada oculta en la tapa inferior, invisible para el usuario de frente.
  * Sonido amplificado por rebote acústico sobre la mesa de trabajo (efecto subwoofer de escritorio).
- Chasis circular compacto de perfil bajo (Ø 118 mm x 34 mm).
"""
import struct
import math
import os

class Mesh3D:
    def __init__(self, name="object"):
        self.name = name
        self.triangles = []

    def add_triangle(self, v1, v2, v3):
        ux, uy, uz = v2[0] - v1[0], v2[1] - v1[1], v2[2] - v1[2]
        vx, vy, vz = v3[0] - v1[0], v3[1] - v1[1], v3[2] - v1[2]
        nx = uy * vz - uz * vy
        ny = uz * vx - ux * vz
        nz = ux * vy - uy * vx
        norm = math.sqrt(nx * nx + ny * ny + nz * nz)
        normal = (nx / norm, ny / norm, nz / norm) if norm > 1e-9 else (0.0, 0.0, 1.0)
        self.triangles.append((normal, v1, v2, v3))

    def add_quad(self, v1, v2, v3, v4):
        self.add_triangle(v1, v2, v3)
        self.add_triangle(v1, v3, v4)

    def add_box(self, x, y, z, dx, dy, dz):
        p0, p1 = (x, y, z), (x + dx, y, z)
        p2, p3 = (x + dx, y + dy, z), (x, y + dy, z)
        p4, p5 = (x, y, z + dz), (x + dx, y, z + dz)
        p6, p7 = (x + dx, y + dy, z + dz), (x, y + dy, z + dz)
        self.add_quad(p0, p3, p2, p1)
        self.add_quad(p4, p5, p6, p7)
        self.add_quad(p0, p1, p5, p4)
        self.add_quad(p3, p7, p6, p2)
        self.add_quad(p0, p4, p7, p3)
        self.add_quad(p1, p2, p6, p5)

    def add_cylinder(self, cx, cy, cz, r, h, segments=64):
        top_pts, bot_pts = [], []
        for i in range(segments):
            th = 2.0 * math.pi * i / segments
            bot_pts.append((cx + r * math.cos(th), cy + r * math.sin(th), cz))
            top_pts.append((cx + r * math.cos(th), cy + r * math.sin(th), cz + h))

        c_bot, c_top = (cx, cy, cz), (cx, cy, cz + h)
        for i in range(segments):
            ni = (i + 1) % segments
            self.add_triangle(c_bot, bot_pts[ni], bot_pts[i])
            self.add_triangle(c_top, top_pts[i], top_pts[ni])
            self.add_quad(bot_pts[i], bot_pts[ni], top_pts[ni], top_pts[i])

    def add_cone_frustum(self, cx, cy, cz, r_bot, r_top, h, segments=64):
        top_pts, bot_pts = [], []
        for i in range(segments):
            th = 2.0 * math.pi * i / segments
            bot_pts.append((cx + r_bot * math.cos(th), cy + r_bot * math.sin(th), cz))
            top_pts.append((cx + r_top * math.cos(th), cy + r_top * math.sin(th), cz + h))

        c_bot, c_top = (cx, cy, cz), (cx, cy, cz + h)
        for i in range(segments):
            ni = (i + 1) % segments
            self.add_triangle(c_bot, bot_pts[ni], bot_pts[i])
            self.add_triangle(c_top, top_pts[i], top_pts[ni])
            self.add_quad(bot_pts[i], bot_pts[ni], top_pts[ni], top_pts[i])

    def add_pipe_segment(self, cx, cy, cz, r_in, r_out, h, segments=64):
        for i in range(segments):
            th1 = 2.0 * math.pi * i / segments
            th2 = 2.0 * math.pi * (i + 1) / segments

            b_in1 = (cx + r_in * math.cos(th1), cy + r_in * math.sin(th1), cz)
            b_in2 = (cx + r_in * math.cos(th2), cy + r_in * math.sin(th2), cz)
            b_out1 = (cx + r_out * math.cos(th1), cy + r_out * math.sin(th1), cz)
            b_out2 = (cx + r_out * math.cos(th2), cy + r_out * math.sin(th2), cz)

            t_in1 = (b_in1[0], b_in1[1], cz + h)
            t_in2 = (b_in2[0], b_in2[1], cz + h)
            t_out1 = (b_out1[0], b_out1[1], cz + h)
            t_out2 = (b_out2[0], b_out2[1], cz + h)

            self.add_quad(b_out1, b_out2, b_in2, b_in1)
            self.add_quad(t_out1, t_in1, t_in2, t_out2)
            self.add_quad(b_out1, t_out1, t_out2, b_out2)
            self.add_quad(b_in1, b_in2, t_in2, t_in1)

    def write_binary_stl(self, filepath):
        header = f"mate-platform {self.name}".encode('ascii')[:80].ljust(80, b'\0')
        count = len(self.triangles)
        with open(filepath, 'wb') as f:
            f.write(header)
            f.write(struct.pack('<I', count))
            for normal, v1, v2, v3 in self.triangles:
                f.write(struct.pack('<3f', normal[0], normal[1], normal[2]))
                f.write(struct.pack('<3f', v1[0], v1[1], v1[2]))
                f.write(struct.pack('<3f', v2[0], v2[1], v2[2]))
                f.write(struct.pack('<3f', v3[0], v3[1], v3[2]))
                f.write(struct.pack('<H', 0))
        print(f"[STL OK] {os.path.basename(filepath)}: {count} tris ({os.path.getsize(filepath)/1024:.1f} KB)")


# ----------------------------------------------------------------------------
# 1. PIEZA 1: CUENCO HUNDIDO BASCULANTE 45° (Deep Anti-Fall Cradle)
# ----------------------------------------------------------------------------
def build_tilting_cradle():
    m = Mesh3D("tilting_cradle")
    r_cup_bottom = 31.0   # Ø 62 mm en fondo
    r_cup_top = 39.0      # Ø 78 mm en boca
    r_cradle_outer = 45.0 # Ø 90 mm exterior
    depth = 18.0          # 18 mm de hundimiento del mate (reborde queda a -10 mm del bisel)
    floor_thick = 4.0

    m.add_cylinder(0, 0, 0, r_cup_bottom + 4.0, floor_thick, segments=64)
    m.add_pipe_segment(0, 0, floor_thick, r_cup_bottom, r_cradle_outer, 10.0, segments=64)
    m.add_pipe_segment(0, 0, floor_thick + 10.0, r_cup_top - 2.0, r_cradle_outer, depth - 10.0, segments=64)
    m.add_cone_frustum(0, 0, floor_thick + depth, r_cradle_outer, r_cradle_outer - 1.5, 2.0, segments=64)

    # Nervios interiores de retención
    for i in range(4):
        ang = i * (math.pi / 2.0)
        nx = (r_cup_bottom - 1.0) * math.cos(ang)
        ny = (r_cup_bottom - 1.0) * math.sin(ang)
        m.add_box(nx - 1.5, ny - 1.5, floor_thick, 3.0, 3.0, depth * 0.7)

    # Pernos de pivote laterales reforzados (Ø 7 mm)
    pin_r = 3.5
    pin_len = 8.0
    pivot_z = floor_thick + 10.0
    m.add_cylinder(r_cradle_outer - 1.0, 0, pivot_z, pin_r, pin_len, segments=24)
    m.add_cylinder(-r_cradle_outer - pin_len + 1.0, 0, pivot_z, pin_r, pin_len, segments=24)

    # Horquilla de empuje servo & alojamiento sensor IMU GY-521
    m.add_box(-4.5, -28.0, -8.0, 9.0, 9.0, 8.0)
    m.add_box(-12.0, -10.0, -4.0, 24.0, 20.0, 4.0)

    return m
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

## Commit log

2026-09-05 feat: initial commit for mate-platform with ESP32 firmware, Wokwi simulation, and MCP notifications
2026-09-05 feat(cad): add 3D mechanical specifications, parametric model generator, and production-ready STL files
    [01_tilting_cradle_45deg.stl, 02_main_enclosure_base.stl, 03_upper_sensor_fascia.stl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]
2026-09-05 feat(cad): add interactive WebGL 3D viewer for all parts
2026-09-05 feat(cad): improve tolerances, mechanical grips, and push updated STLs
    [01_tilting_cradle_45deg.stl, 02_main_enclosure_base.stl, 03_upper_sensor_fascia.stl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]
2026-09-05 feat(cad): upgrade Studio 3D viewer with exploded assembly view and servo tilt simulator
2026-09-05 feat(cad): make 3D viewer interactive, fun and simple with pouring simulation
2026-09-05 feat(cad): redesign enclosure into cylindrical/organic MateBot with Minion eyes and UFO base
    [01_tilting_cradle_45deg.stl, 02_main_enclosure_base.stl, 03_upper_sensor_fascia.stl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]
2026-09-05 feat(cad): redesign enclosure into ultra-slim MagSafe circular dock with flush OLED and hidden sensors
    [01_tilting_cradle_45deg.stl, 02_main_enclosure_base.stl, 03_upper_sensor_fascia.stl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]
2026-09-05 feat: implement deep anti-fall sunken cradle, physical crown button and front OLED display
    [01_tilting_cradle_45deg.stl, 02_main_enclosure_base.stl, 03_upper_sensor_fascia.stl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]
2026-09-05 feat: add status LED on bezel, down-firing speaker cavity and bottom acoustic grille
    [02_main_enclosure_base.stl, 03_upper_sensor_fascia.stl, 04_bottom_service_lid.stl]
2026-09-05 fix(cad): sink mate cradle 10mm below bezel, deep pocket through dock body
    [01_tilting_cradle_45deg.stl, 02_main_enclosure_base.stl]
